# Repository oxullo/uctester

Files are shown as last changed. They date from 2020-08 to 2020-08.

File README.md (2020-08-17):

# uctester

Ultimate Continuity tester or Leo's ideal tool for continuity testing.

The design of the tool is described here: https://www.youtube.com/watch?v=N2M-p-OGvPg

A description of an implementation of such design can be found here: https://www.xul.it/blog/index.php/2020/08/15/the-ultimate-continuity-tester/

## Eagle

This repo stores the production files of the tool, with sources for Eagle and a Gerber export. All the files are released under the MIT license, with the permission of the original author.

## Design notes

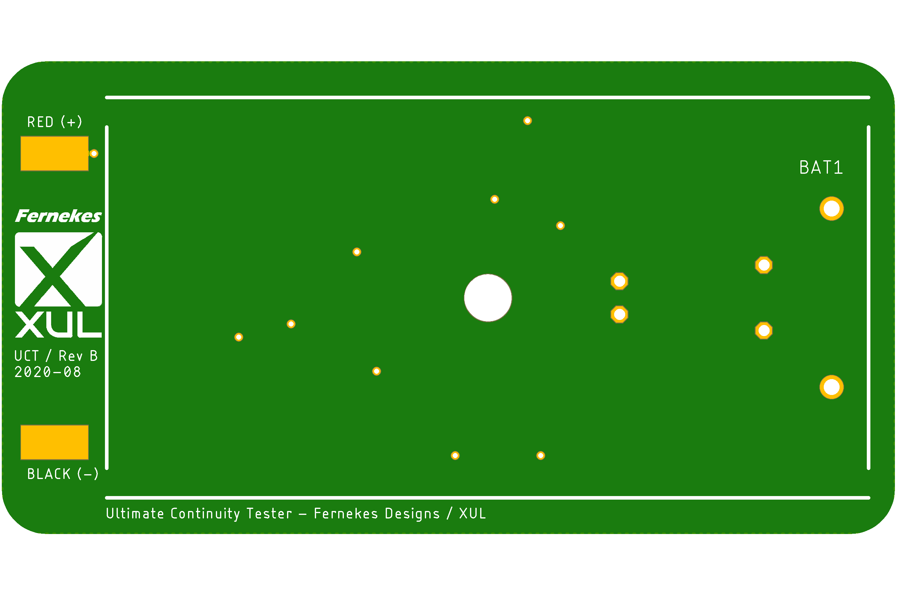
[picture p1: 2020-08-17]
uctester-pcb-top.png

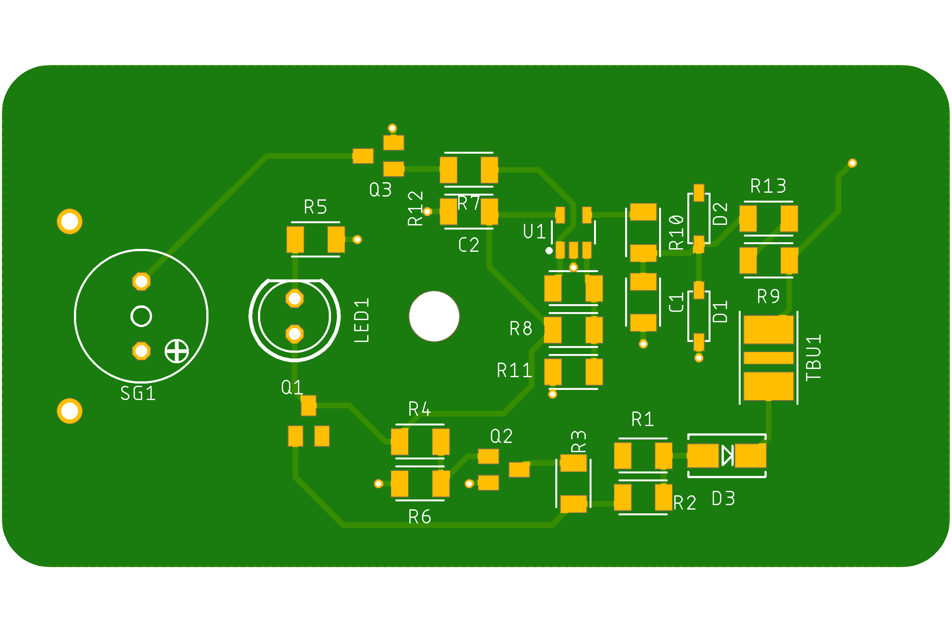
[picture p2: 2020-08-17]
uctester-pcb-bottom.png

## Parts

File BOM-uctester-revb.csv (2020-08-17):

Qty | Value | Device | Package | Parts | Description | Digikey
1 |  | LED5MM | LED5MM | LED1 | LED | 67-1097-ND
2 | 10n | C_CHIP-1206(3216-METRIC) | CAPC3216X135 | C1, C2 | Capacitor - Generic | 478-1542-1-ND
5 | 10k | R_CHIP-1206(3216-METRIC) | RESC3216X70 | R4, R6, R7, R8, R10 | Resistor Fixed - Generic | 311-10.0KFRCT-ND
1 | 160R | R_CHIP-1206(3216-METRIC) | RESC3216X70 | R11 | Resistor Fixed - Generic | 311-160FRCT-ND
1 | 22k | R_CHIP-1206(3216-METRIC) | RESC3216X70 | R12 | Resistor Fixed - Generic | 311-22.0KFRCT-ND
2 | 240R | R_CHIP-1206(3216-METRIC) | RESC3216X70 | R1, R5 | Resistor Fixed - Generic | 311-240FRCT-ND
2 | 510k | R_CHIP-1206(3216-METRIC) | RESC3216X70 | R9, R13 | Resistor Fixed - Generic | 311-510KFRCT-ND
1 | 510R | R_CHIP-1206(3216-METRIC) | RESC3216X70 | R2 | Resistor Fixed - Generic | RMCF1206FT510RCT-ND
1 | 5k | R_CHIP-1206(3216-METRIC) | RESC3216X70 | R3 | Resistor Fixed - Generic | YAG5090CT-ND
1 | AI-1027-TWT | AI-1027-TWT | AI-1027-TWT | SG1 | BUZZER Source: Buerklin | 668-1219-ND
2 | 1N4148W | DIODESOD-123 | SOD-123 | D1, D2 | Diode | 1N4148W-13FDICT-ND
1 | BC2AAPC | BC2AAPC | BC2AAPC | BAT1 | BC2APPC | BC2AAPC-ND
1 | BC807 | BC807-40SMD | SOT23-BEC | Q1 | PNP Transistror | 1727-2917-1-ND
2 | BC817 | BC817-40LT1SMD | SOT23-BEC | Q2, Q3 | NPN Transistor | 1727-2919-1-ND
1 | MCP6021T-E/OT | MCP6021T-E/OT | SOT95P280X145-5N | U1 | MCP6021T-E/OT OP AMP | MCP6021T-E/OTDKR-ND
1 | S1J-E3/61T | S1J-E3/61T | DIODE_DO214AC | D3 |  | S1J-E3/61TGICT-ND
1 | TBU-CA | TBU-CA | RESDFN650X400X90-2N | TBU1 |  | TBU-CA065-050-WHCT-ND
1 |  | Banana sockets |  |  |  | 501-2347-ND

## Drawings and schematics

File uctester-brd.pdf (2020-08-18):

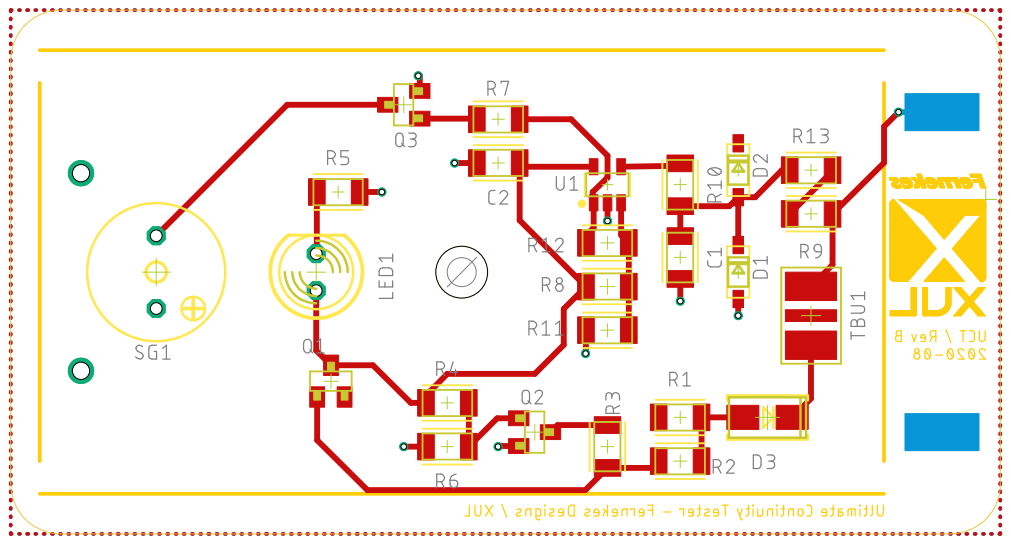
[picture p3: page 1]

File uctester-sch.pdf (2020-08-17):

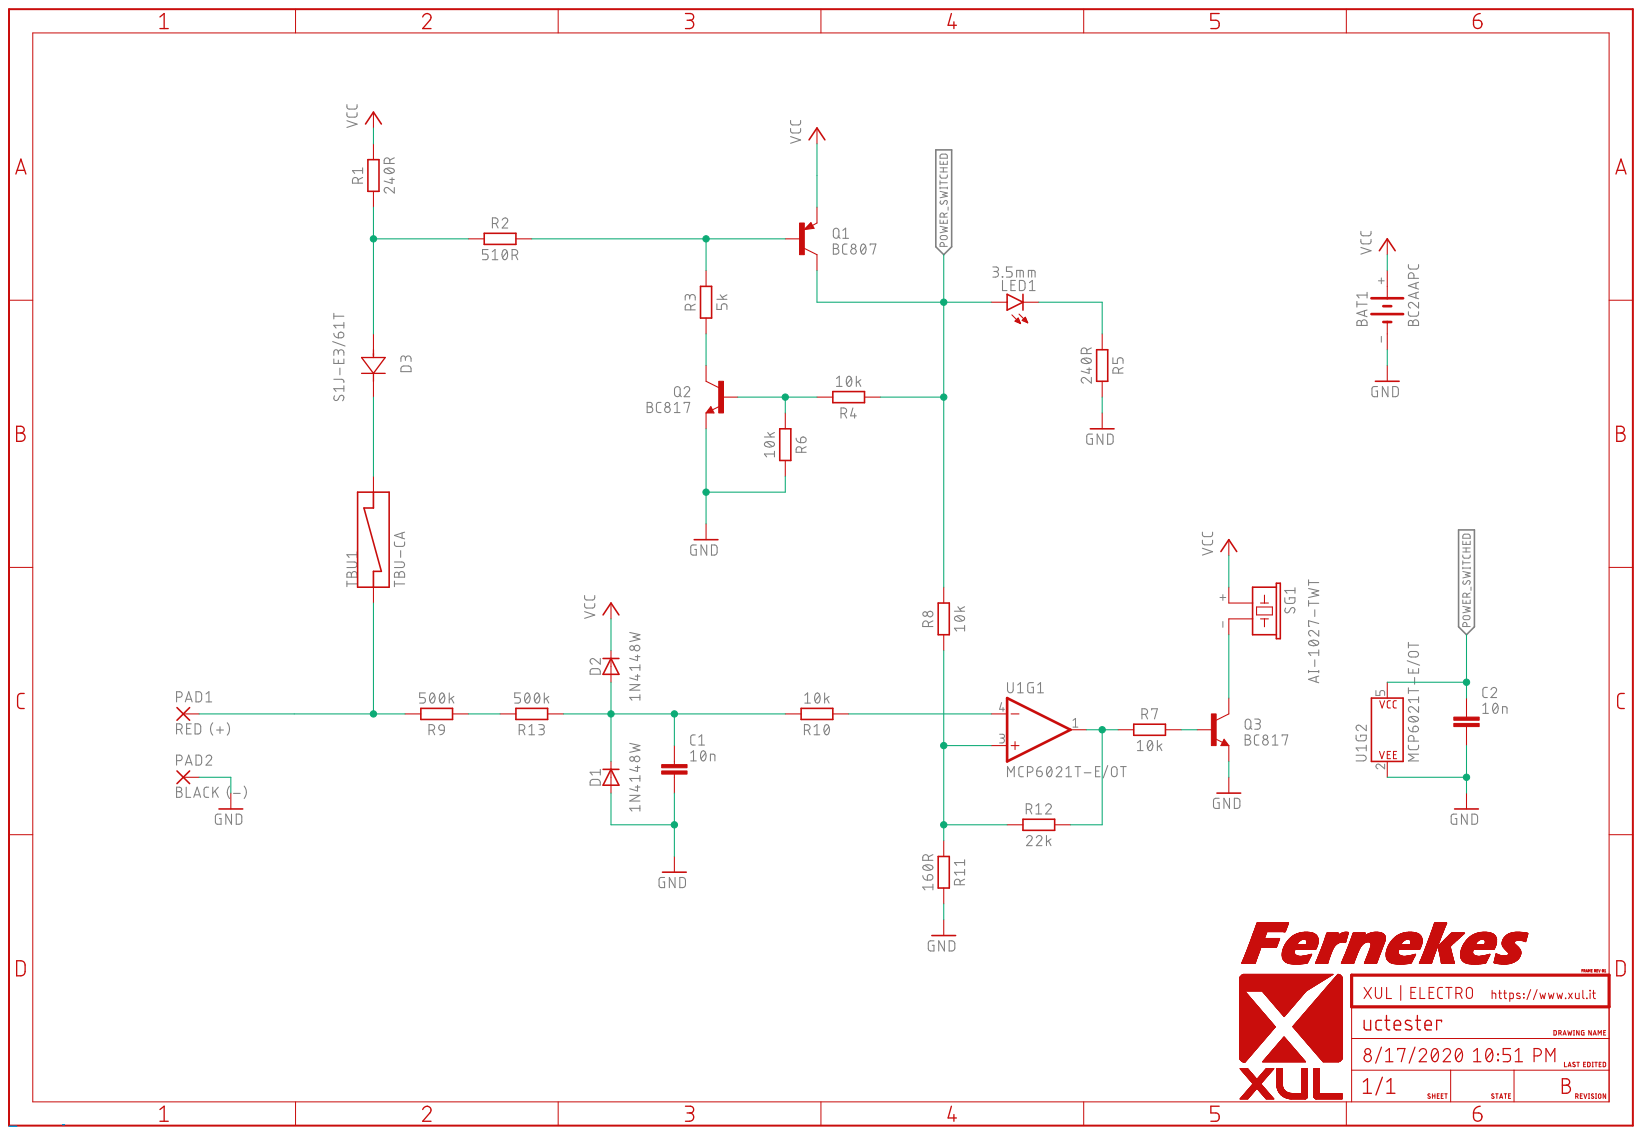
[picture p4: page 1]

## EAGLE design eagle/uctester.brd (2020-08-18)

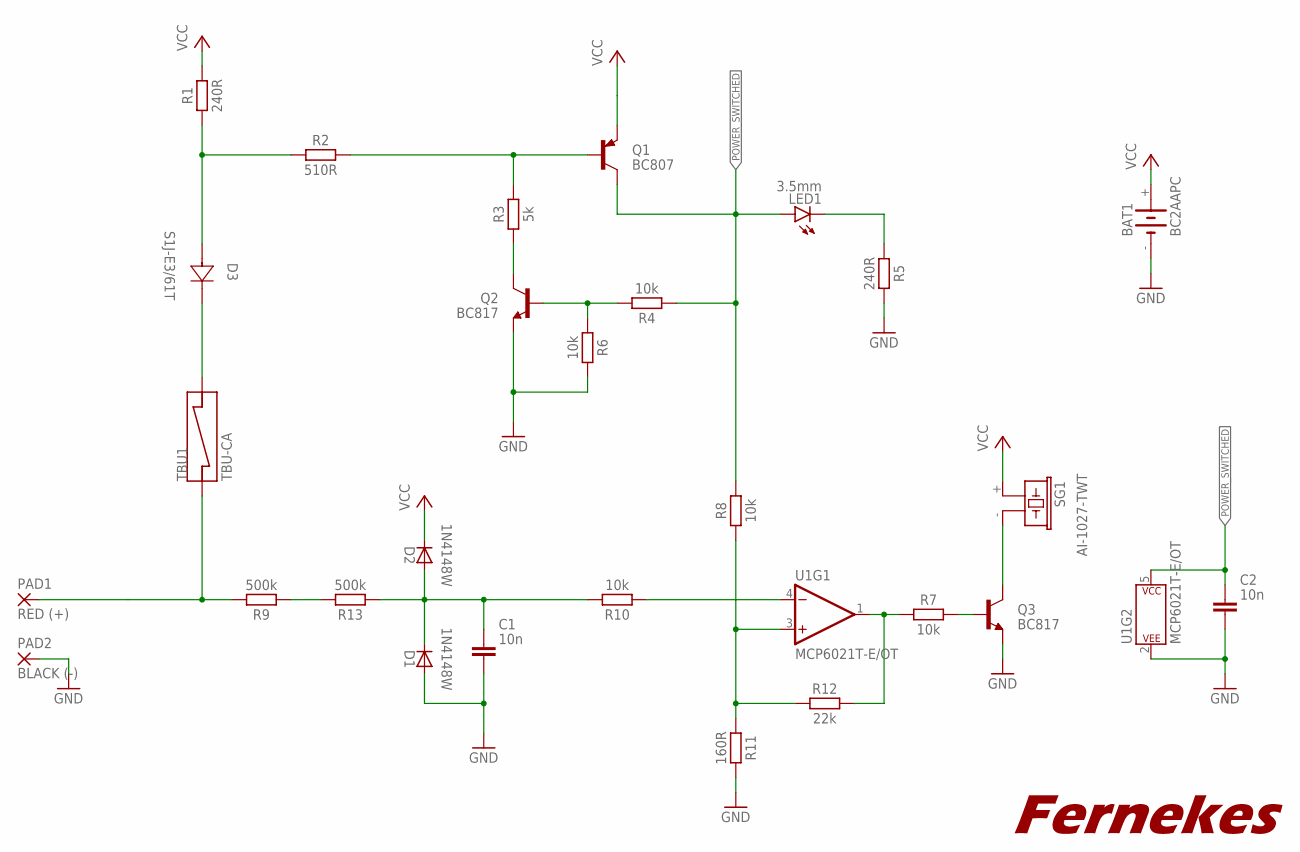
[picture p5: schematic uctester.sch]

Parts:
BAT1: BC2AAPC
C1, C2: 10n; CAPC3216X135
D1, D2: 1N4148W; SOD-123
D3: S1J-E3/61T; DIODE_DO214AC
LED1: 3.5mm; LED5MM
PAD1: RED (+); SMD2,54-5,08
PAD2: BLACK (-); SMD2,54-5,08
Q1: BC807; SOT23-BEC
Q2, Q3: BC817; SOT23-BEC
R1, R5: 240R; RESC3216X70
R2: 510R; RESC3216X70
R3: 5k; RESC3216X70
R4, R6, R7, R8, R10: 10k; RESC3216X70
R9, R13: 500k; RESC3216X70
R11: 160R; RESC3216X70
R12: 22k; RESC3216X70
SG1: AI-1027-TWT
TBU1: TBU-CA; RESDFN650X400X90-2N
U1: MCP6021T-E/OT; SOT95P280X145-5N

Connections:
GND: BAT1.-, C1.2, C2.2, D1.A, PAD2.1, Q2.E, Q3.E, R5.2, R6.2, R11.2, U1.2 (P$V-)
unnamed: Q2.C, R3.1
unnamed: Q2.B, R4.2, R6.1
unnamed: R9.1, R13.2
unnamed: R10.1, U1.4 (-IN)
unnamed: R8.1, R11.1, R12.1, U1.3 (+IN)
unnamed: R7.1, R12.2, U1.1 (OUT)
unnamed: Q3.B, R7.2
unnamed: Q3.C, SG1.- (2)
unnamed: Q1.B, R2.2, R3.2
unnamed: C1.1, D1.C, D2.A, R10.2, R13.1
unnamed: D3.2 (A), R1.1, R2.1
unnamed: PAD1.1, R9.2, TBU1.1
unnamed: LED1.K (C), R5.1
unnamed: D3.1 (C), TBU1.3
POWER_SWITCHED: C2.1, LED1.A, Q1.C, R4.1, R8.2, U1.5 (P$V+)
VCC: BAT1.+, D2.C, Q1.E, R1.2, SG1.+ (1)

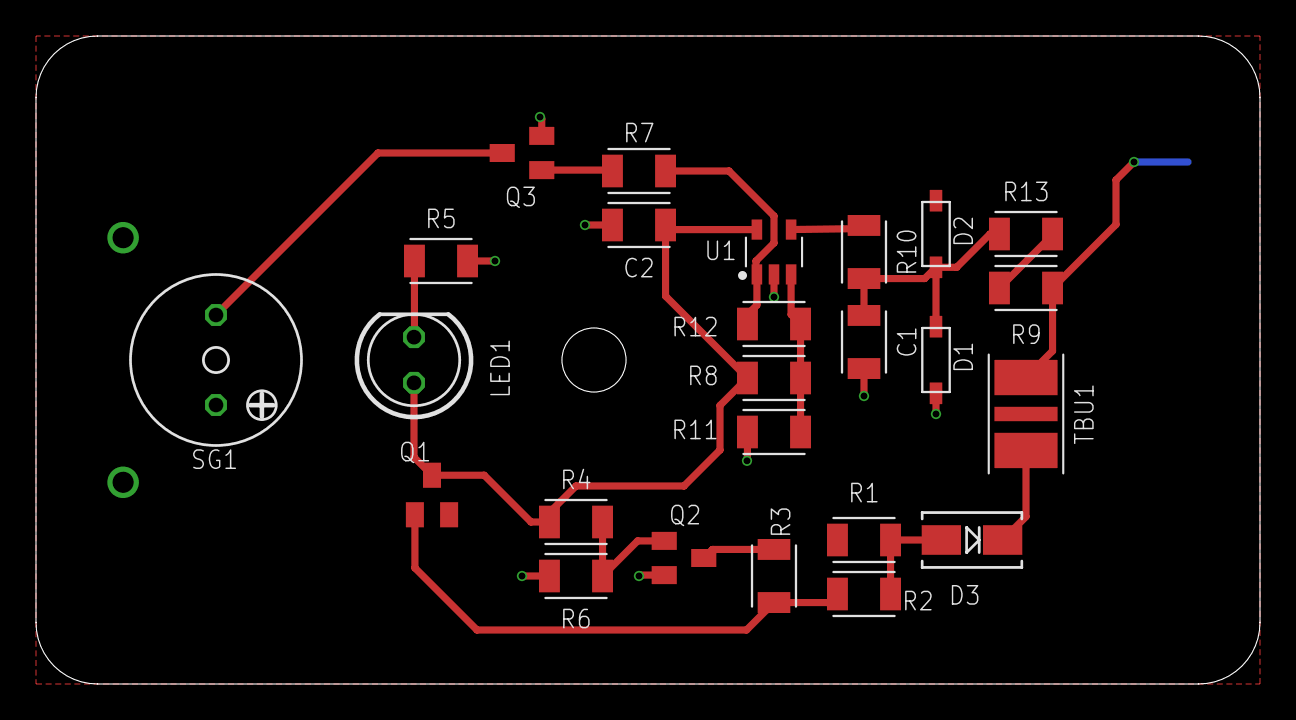
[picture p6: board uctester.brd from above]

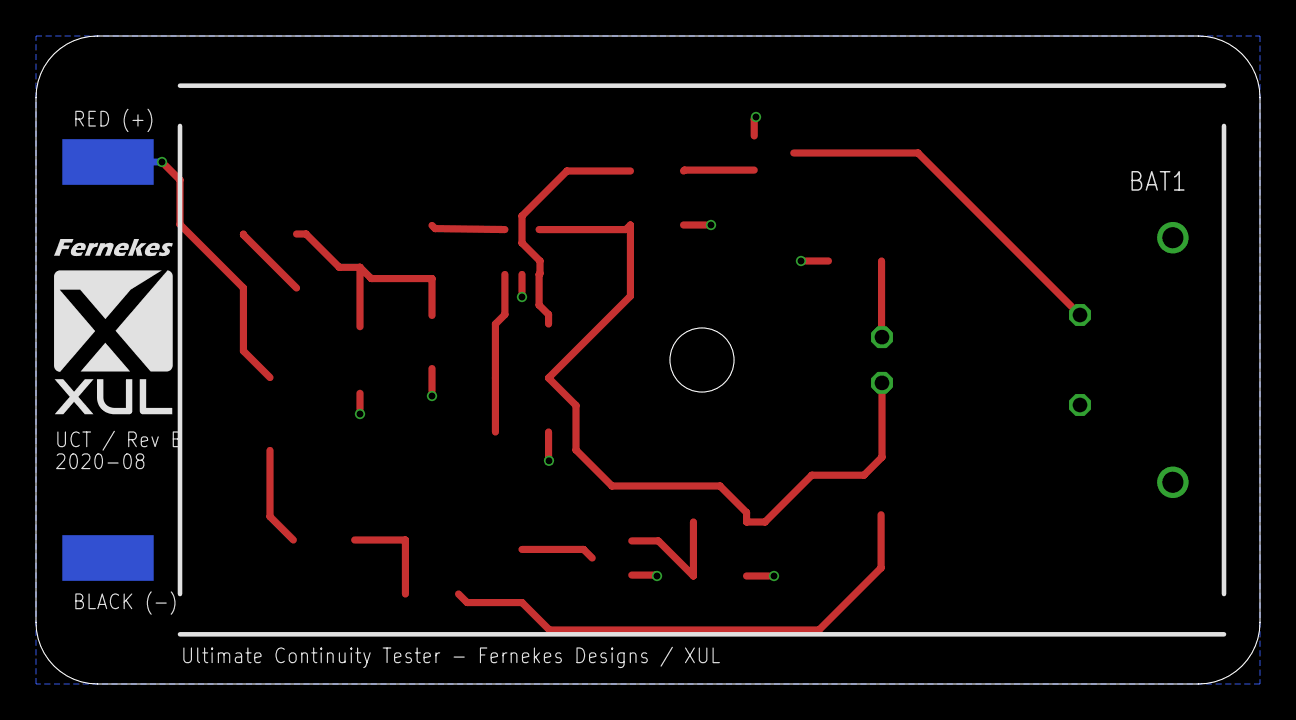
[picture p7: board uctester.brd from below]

Board: 2 copper layers, 68.0 x 36.0 mm, 29 parts (4 on the bottom side), 17 nets.

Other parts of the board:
U$1: XUL-LOGO-8MMH

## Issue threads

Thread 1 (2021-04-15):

Add bigger clearances on hot paths for more safety

ri0t, 2021-04-15:
Ahoi!
Nice design. I suggest adding a little bit more clearance to possibly hot pathways.
This (comprehensive and handy) list of safe and "deadly" AC->USB-converters shows a lot of examples on how to do it right (and how not):
https://lygte-info.dk/info/ChargerIndex%20UK.html

Here's [a picture of a unit](https://lygte-info.dk/pic/USB%20PS/243%20Baseus%20Speed%20PPS%20Quick%20Charger%20USB%2BType%20C%2030W%20BS-EU905/DSC_2342.jpg) wich was tested against 4kV.
One trick is to use non-conducting material (e.g. hot glue) for isolation purposes, but this makes everything very messy.

oxullo, 2021-06-12:
Thanks for the hint and the link, I keep this issue open for a future revision C!

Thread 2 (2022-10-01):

TBU1 Pads

yngndrw, 2022-10-01:
Hello,

According to the [datasheet](https://www.bourns.com/data/global/pdfs/TBU-CA.pdf) (Page 4), the TBU-CA protection device for thermal reasons. I'm not sure it's strictly necessary in this design, but it's best practice to follow the datasheet guidance where reasonable. They don't give specific dimensions, but their example appears to be approximately double the size of each of the conductor pads.

As an aside, do you think that the [TBU-CA085-100-WH](https://jlcpcb.com/partdetail/Bourns-TBU_CA085_100WH/C720638) would be a suitable replacement? I ask because it's the closest value which JLCPCB stock. The 85 means that it has an absolute maximum input voltage of 850V rather than 500V, but the 100 means that the trigger current is around 150mA rather than 75mA which I think should be fine - Worst-case R1 will dissipate around 5x the power it would have done with the TBU-CA050-050 but that's only for around 1uS.

oxullo, 2022-10-03:
Hey @yngndrw,
I tried to dig into the matter of your aside-question in a post that you can find here: https://www.xul.it/blog/index.php/2022/10/03/power-cross-protection-in-the-uct/
TLDR: it should be ok :)

Regarding the footprint of the device, I followed the guidelines:

>  It is recommended that they should be the same dimension as the TBU® pads

(still page 4). As also mentioned there, increasing the pads would improve the thermal resistance, but given the triggering speed, quiescent and operating current of the device, I personally find it unnecessary.

One reason to extend the pads would be to slightly improve solderability, as it's quite complicated to see whether the pads have properly reflown when soldering by hand.
Besides, you can also see how Bourns itself didn't add any padding in their EVBs: https://www.bourns.com/docs/products-general/bourns_fu1106_rs-485_evalboard_designnote_1.pdf

I'll close the ticket, but please reopen if you disagree. In such case I'd be grateful if you'd provide a footprint. Thanks!

Closed 2022-10-03.

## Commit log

2020-08-17 Initial import of the latest design
    [BOM-uctester-revb.csv, uctester.brd, uctester.sch]
2020-08-18 Fix R12's silkscreen name position
    [uctester.brd]
